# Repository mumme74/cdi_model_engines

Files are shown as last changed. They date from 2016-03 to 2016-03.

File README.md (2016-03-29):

# CDI for model engines
A CDI driven by 12v to be used by model engines

# Warning this project isnt tested nor testbuilt yet

Its for my brother next model engine that he's building, a Hoglet.

Features:
 * Should (in theory) support a 12Cyl up to 6000 rpm
 * 2 wire hallsensor solution (like a GME)
 * Hallsensor trigger output to optional other board (like a arduino)
 * Optionally trigger from a input instead of hallsensor (remove a solder bridge)
 
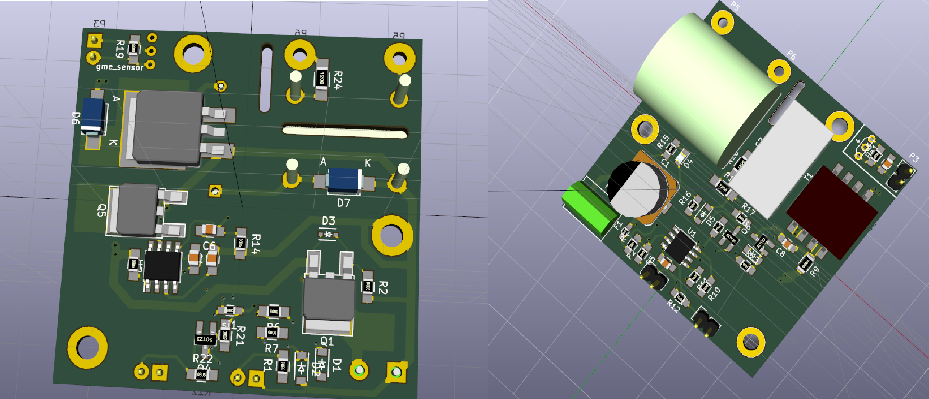
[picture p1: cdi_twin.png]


Should be able to run his challenger V8
https://www.youtube.com/watch?v=TyKyQjUpV_E

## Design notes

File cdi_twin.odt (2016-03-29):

CDI 12v

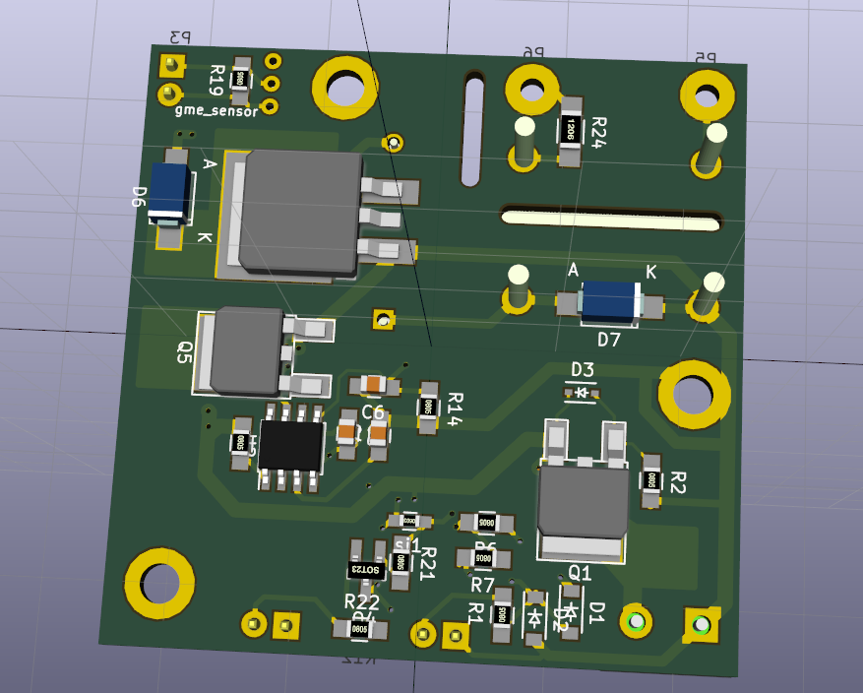
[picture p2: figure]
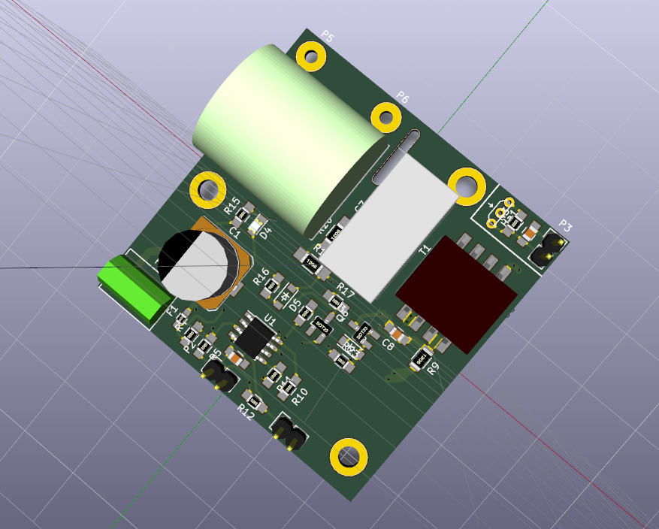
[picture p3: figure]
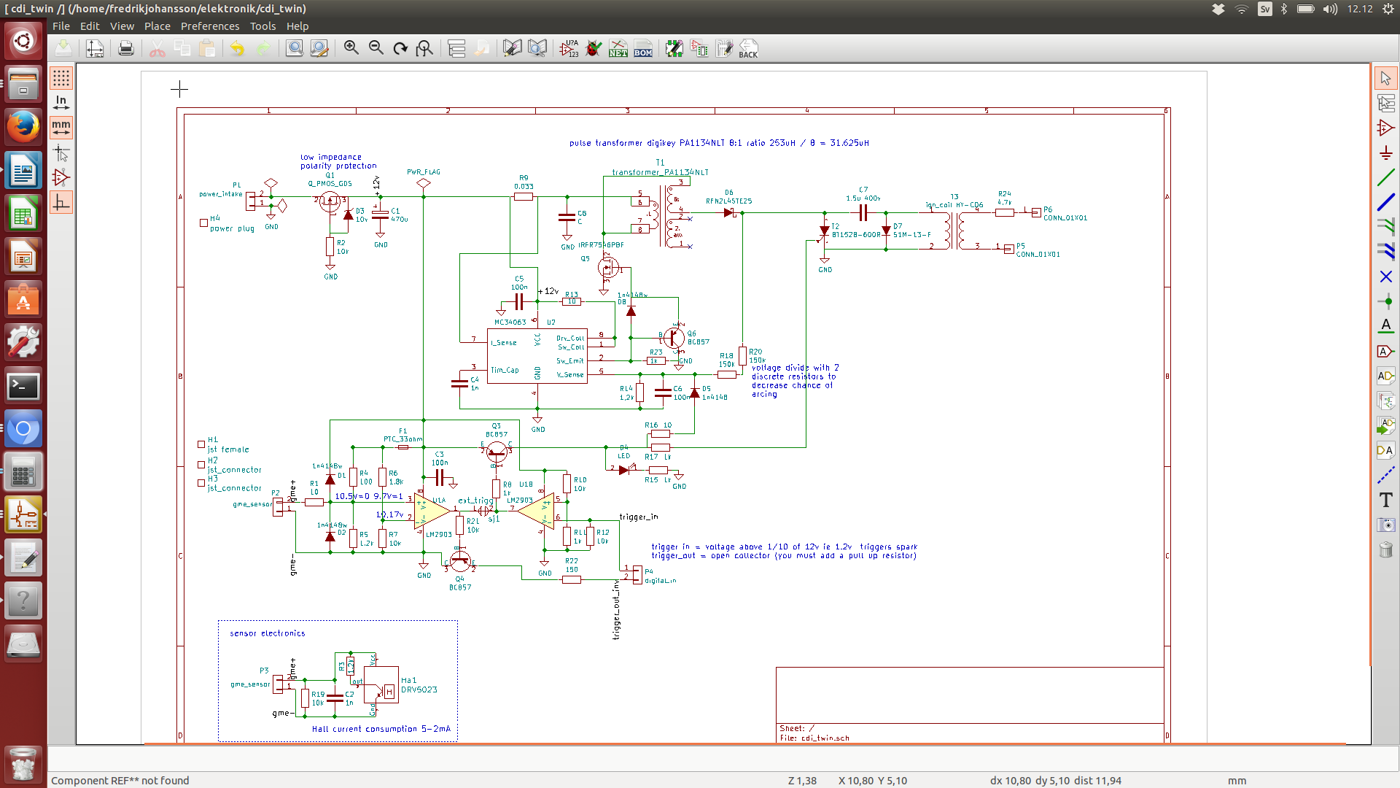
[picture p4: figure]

All prices are in SEK.
Index | Quantity | Image | Part Number | Description | Customer Reference | Available Quantity | Backorder Quantity | Unit Price | Extended Price
1 | | | 1N4148W-FDICT-ND (http://www.digikey.se/scripts/DkSearch/dksus.dll?Detail&itemSeq=193125955&uq=635947423000948024) | DIODE GEN PURP 100V 300MA SOD123 | | 4 Immediate | 0 | 1,37000 | 5,48 kr
2 | | | 296-1012-1-ND (http://www.digikey.se/scripts/DkSearch/dksus.dll?Detail&itemSeq=193125954&uq=635947423000948024) | IC DUAL DIFF COMP 8-SOIC | | 1 Immediate | 0 | 3,17000 | 3,17 kr
3 | | | 296-38520-ND (http://www.digikey.se/scripts/DkSearch/dksus.dll?Detail&itemSeq=193125950&uq=635947423000958024) | IC HALL SENSOR DGTL SW TO-92 | | 1 Immediate | 0 | 9,60000 | 9,60 kr
4 | | | 311-1.00KCRCT-ND (http://www.digikey.se/scripts/DkSearch/dksus.dll?Detail&itemSeq=193125953&uq=635947423000958024) | RES SMD 1K OHM 1% 1/8W 0805 | | 5 Immediate | 0 | 0,86000 | 4,30 kr
5 | | | 311-1.20KCRCT-ND (http://www.digikey.se/scripts/DkSearch/dksus.dll?Detail&itemSeq=193125949&uq=635947423000958024) | RES SMD 1.2K OHM 1% 1/8W 0805 | | 3 Immediate | 0 | 0,86000 | 2,58 kr
6 | | | 311-1.80KCRCT-ND (http://www.digikey.se/scripts/DkSearch/dksus.dll?Detail&itemSeq=193125951&uq=635947423000968024) | RES SMD 1.8K OHM 1% 1/8W 0805 | | 1 Immediate | 0 | 0,86000 | 0,86 kr
7 | | | 311-10.0CRCT-ND (http://www.digikey.se/scripts/DkSearch/dksus.dll?Detail&itemSeq=193125947&uq=635947423000968024) | RES SMD 10 OHM 1% 1/8W 0805 | | 3 Immediate | 0 | 0,86000 | 2,58 kr
8 | | | 311-10.0KCRCT-ND (http://www.digikey.se/scripts/DkSearch/dksus.dll?Detail&itemSeq=193125952&uq=635947423000968024) | RES SMD 10K OHM 1% 1/8W 0805 | | 6 Immediate | 0 | 0,86000 | 5,16 kr
9 | | | 311-100CRCT-ND (http://www.digikey.se/scripts/DkSearch/dksus.dll?Detail&itemSeq=193125946&uq=635947423000978024) | RES SMD 100 OHM 1% 1/8W 0805 | | 1 Immediate | 0 | 0,86000 | 0,86 kr
10 | | | 311-150CRCT-ND (http://www.digikey.se/scripts/DkSearch/dksus.dll?Detail&itemSeq=193125948&uq=635947423000978024) | RES SMD 150 OHM 1% 1/8W 0805 | | 1 Immediate | 0 | 0,86000 | 0,86 kr
11 | | | 311-150KERCT-ND (http://www.digikey.se/scripts/DkSearch/dksus.dll?Detail&itemSeq=193125944&uq=635947423000978024) | RES SMD 150K OHM 5% 1/4W 1206 | | 2 Immediate | 0 | 0,86000 | 1,72 kr
12 | | | 311-4.7ERCT-ND (http://www.digikey.se/scripts/DkSearch/dksus.dll?Detail&itemSeq=193125945&uq=635947423000988024) | RES SMD 4.7 OHM 5% 1/4W 1206 | | 1 Immediate | 0 | 0,86000 | 0,86 kr
13 | | | 408-1576-1-ND (http://www.digikey.se/scripts/DkSearch/dksus.dll?Detail&itemSeq=193125942&uq=635947423000988024) | RES SMD 0.033 OHM 1% 3/4W 1206 | | 1 Immediate | 0 | 4,63000 | 4,63 kr
14 | | | 455-1135-1-ND (http://www.digikey.se/scripts/DkSearch/dksus.dll?Detail&itemSeq=193125943&uq=635947423000988024) | CONN TERM CRIMP XH 22-28AWG | | 2 Immediate | 0 | 0,86000 | 1,72 kr
15 | | | 455-2247-ND (http://www.digikey.se/scripts/DkSearch/dksus.dll?Detail&itemSeq=193125938&uq=635947423000998024) | CONN HEADER XH TOP 2POS 2.5MM | | 2 Immediate | 0 | 1,29000 | 2,58 kr
16 | | | 455-2266-ND (http://www.digikey.se/scripts/DkSearch/dksus.dll?Detail&itemSeq=193125940&uq=635947423000998024) | CONN HOUSING 2.5MM 2POS | | 1 Immediate | 0 | 0,86000 | 0,86 kr
17 | | | 478-1328-1-ND (http://www.digikey.se/scripts/DkSearch/dksus.dll?Detail&itemSeq=193125939&uq=635947423001008024) | CAP CER 1000PF 50V NP0 0805 | | 3 Immediate | 0 | 0,86000 | 2,58 kr
18 | | | 478-3352-1-ND (http://www.digikey.se/scripts/DkSearch/dksus.dll?Detail&itemSeq=193125937&uq=635947423001008024) | CAP CER 0.1UF 50V X7R 0805 | | 3 Immediate | 0 | 0,86000 | 2,58 kr
19 | | | 490-2471-1-ND (http://www.digikey.se/scripts/DkSearch/dksus.dll?Detail&itemSeq=193125941&uq=635947423001008024) | THERMISTOR PTC 33 OHM SMD | | 1 Immediate | 0 | 4,63000 | 4,63 kr
20 | | | 493-6225-1-ND (http://www.digikey.se/scripts/DkSearch/dksus.dll?Detail&itemSeq=193125936&uq=635947423001018024) | CAP ALUM 470UF 20% 25V SMD | | 1 Immediate | 0 | 5,83000 | 5,83 kr
21 | | | 497-7851-1-ND (http://www.digikey.se/scripts/DkSearch/dksus.dll?Detail&itemSeq=193125935&uq=635947423001018024) | IC REG BUCK BOOST INV ADJ 8SOIC | | 1 Immediate | 0 | 4,80000 | 4,80 kr
22 | | | 553-1982-1-ND (http://www.digikey.se/scripts/DkSearch/dksus.dll?Detail&itemSeq=193125933&uq=635947423001018024) | XFRMR 5V 7W 253UH POE EP10 SMD | | 1 Immediate | 0 | 31,97000 | 31,97 kr
23 | | | 568-9619-1-ND (http://www.digikey.se/scripts/DkSearch/dksus.dll?Detail&itemSeq=193125931&uq=635947423001028024) | THYRISTOR 650V 20A D2PAK | | 1 Immediate | 0 | 10,20000 | 10,20 kr
24 | | | 732-4986-1-ND (http://www.digikey.se/scripts/DkSearch/dksus.dll?Detail&itemSeq=193125932&uq=635947423001028024) | LED GREEN CLEAR 0805 SMD | | 1 Immediate | 0 | 2,83000 | 2,83 kr
25 | | | BC857ALT1GOSCT-ND (http://www.digikey.se/scripts/DkSearch/dksus.dll?Detail&itemSeq=193125934&uq=635947423001028024) | TRANS PNP 45V 0.1A SOT-23 | | 3 Immediate | 0 | 1,03000 | 3,09 kr
26 | | | DMP3010LK3Q-13DICT-ND (http://www.digikey.se/scripts/DkSearch/dksus.dll?Detail&itemSeq=193125930&uq=635947423001038024) | MOSFET P-CH 30V 17A TO252 | | 1 Immediate | 0 | 5,31000 | 5,31 kr
27 | | | ED2828-ND (http://www.digikey.se/scripts/DkSearch/dksus.dll?Detail&itemSeq=193125929&uq=635947423001038024) | TERM BLOCK HDR 2POS R/A 5.08MM | | 1 Immediate | 0 | 2,31000 | 2,31 kr
28 | | | ED2908-ND (http://www.digikey.se/scripts/DkSearch/dksus.dll?Detail&itemSeq=193125925&uq=635947423001038024) | TERM BLOCK PLUG 2POS STR 5.08MM | | 1 Immediate | 0 | 7,54000 | 7,54 kr
29 | | | IRFR7546PBF-ND (http://www.digikey.se/scripts/DkSearch/dksus.dll?Detail&itemSeq=193125924&uq=635947423001048024) | MOSFET N-CH 60V 56A DPAK | | 1 Immediate | 0 | 7,03000 | 7,03 kr
30 | | | MM3Z10VT1GOSCT-ND (http://www.digikey.se/scripts/DkSearch/dksus.dll?Detail&itemSeq=193125926&uq=635947423001048024) | DIODE ZENER 10V 300MW SOD323 | | 1 Immediate | 0 | 1,20000 | 1,20 kr
31 | | | PCF1613-ND (http://www.digikey.se/scripts/DkSearch/dksus.dll?Detail&itemSeq=193125923&uq=635947423001048024) | CAP FILM 1.5UF 5% 450VDC RADIAL | | 1 Immediate | 0 | 6,86000 | 6,86 kr
32 | | | RFN2L4STE25CT-ND (http://www.digikey.se/scripts/DkSearch/dksus.dll?Detail&itemSeq=193125927&uq=635947423001058024) | DIODE SCHOTTKY 400V 1.5A PMDS | | 1 Immediate | 0 | 4,63000 | 4,63 kr
33 | | | S1M-FDICT-ND (http://www.digikey.se/scripts/DkSearch/dksus.dll?Detail&itemSeq=193125928&uq=635947423001058024) | DIODE GEN PURP 1KV 1A SMA | | 1 Immediate | 0 | 2,06000 | 2,06 kr
| | | | | | | | Subtotal | 153,27 kr
| | | | | | | | Shipping | 170,00 kr
| | | | | | | | Total | unknown

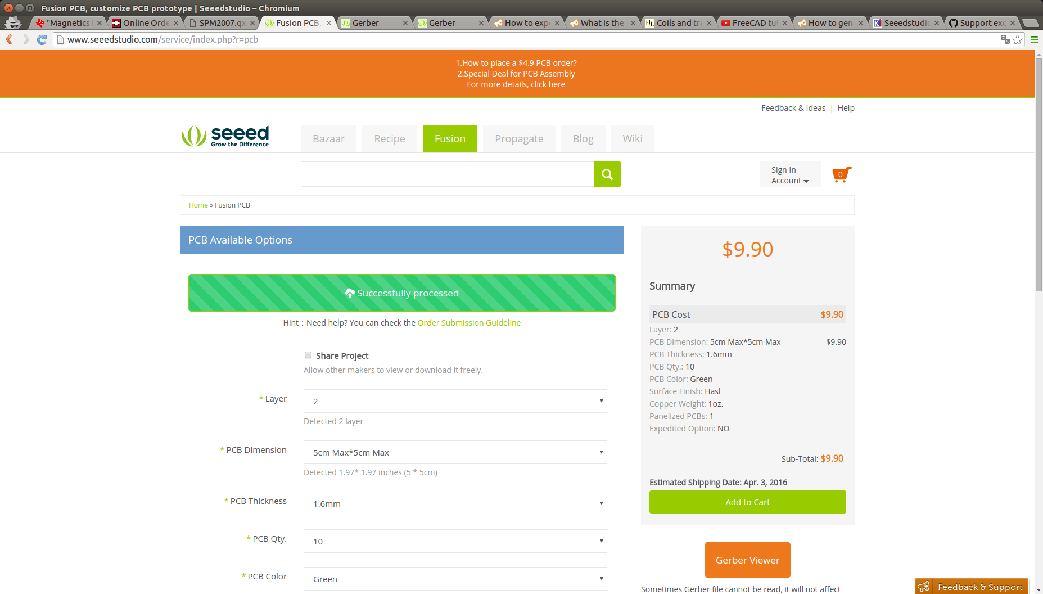
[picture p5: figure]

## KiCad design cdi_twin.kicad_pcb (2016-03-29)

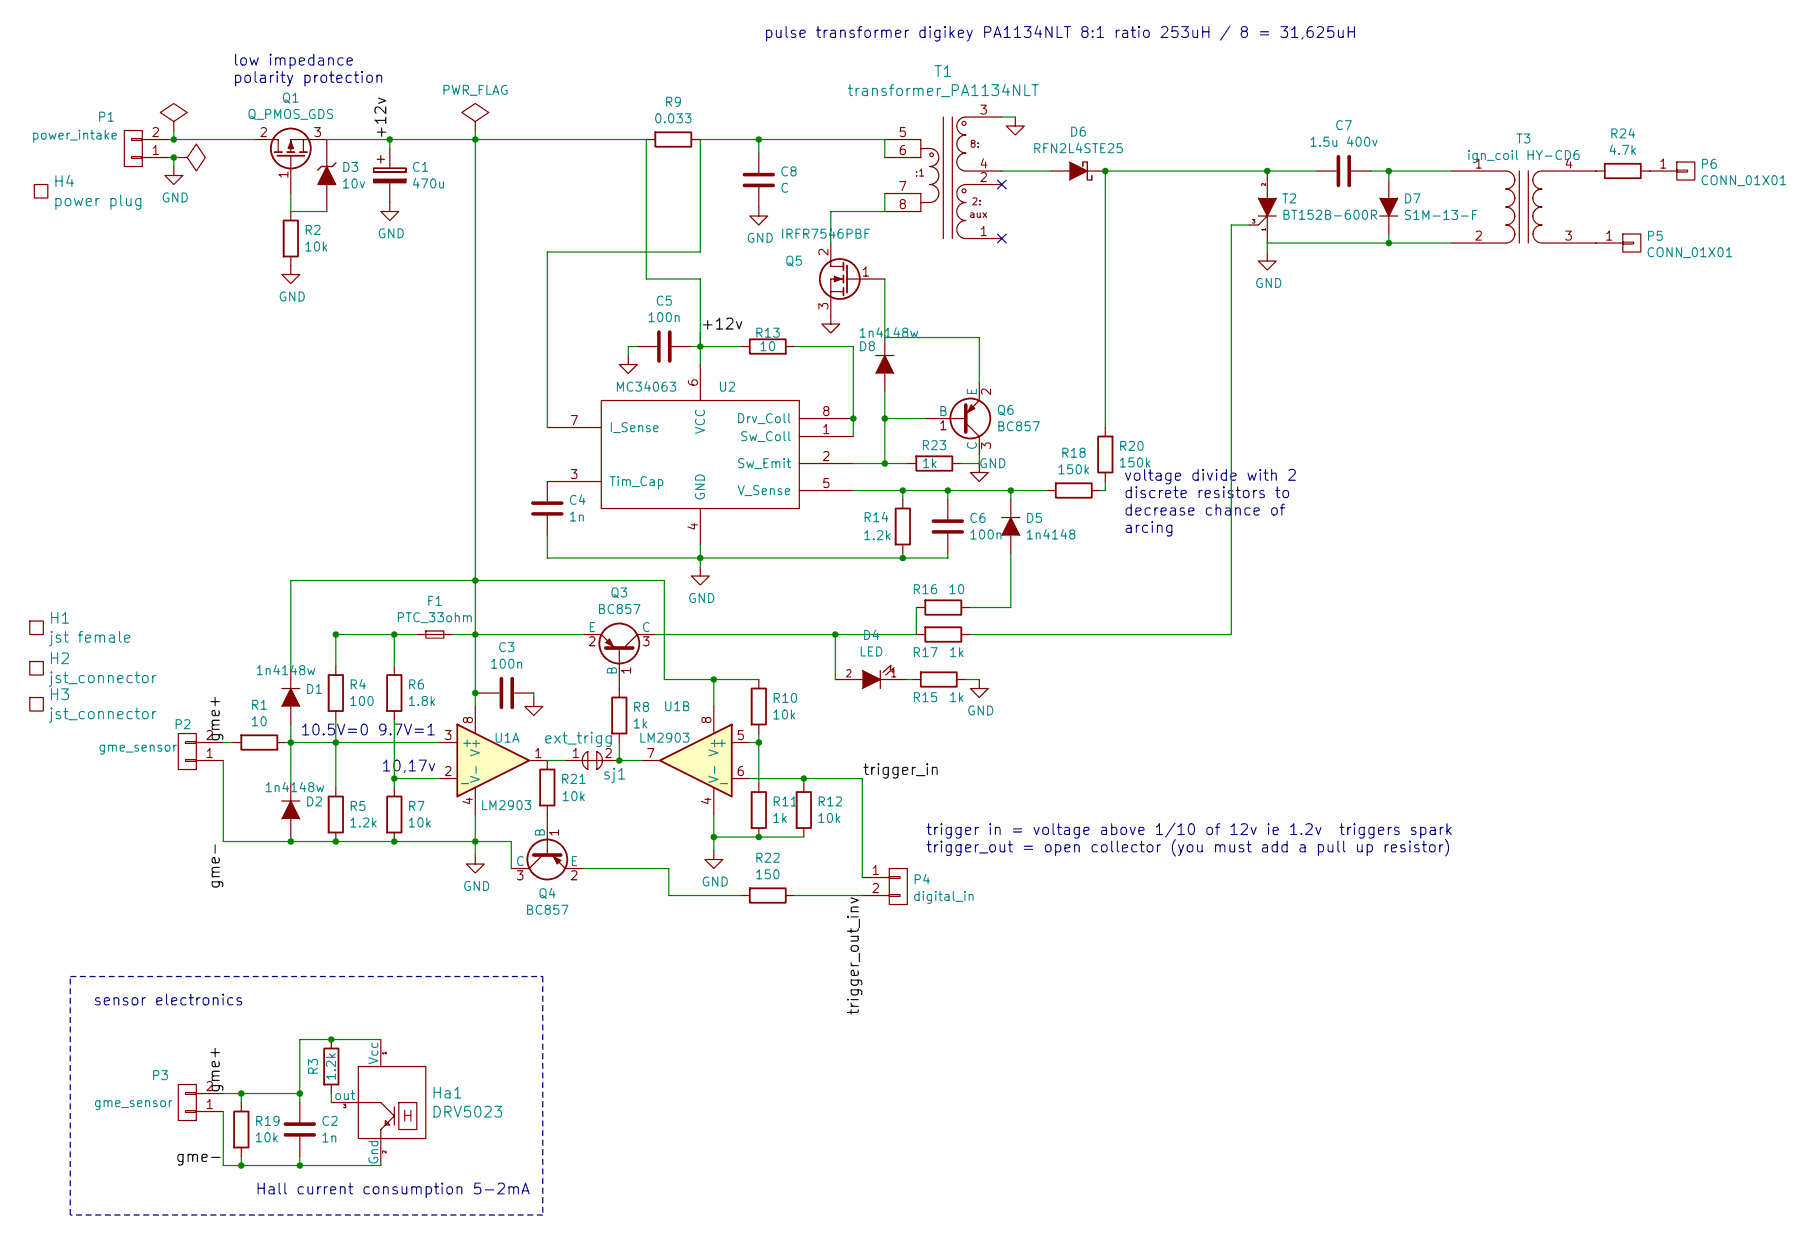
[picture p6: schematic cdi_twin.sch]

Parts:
C1: 470u; c_elec_10x10; digikey 493-6225-1-ND
C2, C4: 1n; C_0805_HandSoldering; digikey 478-1328-1-ND
C3, C5, C6: 100n; C_0805_HandSoldering; digikey 478-3352-1-ND
C7: 1.5u 400v; C_Rect_L18_W9_H15_P15; digikey PCF1613-ND
C8: C; C_0805_HandSoldering; digikey 478-1328-1-ND
D1, D2, D8: 1n4148w; SOD-123; digikey 1N4148W-FDICT-ND
D3: 10v; SOD-323; digikey MM3Z10VT1GOSCT-ND
D4: LED; LED_0805; digikey 732-4986-1-ND
D5: 1n4148; SOD-123; digikey 1N4148W-FDICT-ND
D6: RFN2L4STE25; SMA_Handsoldering; digikey RFN2L4STE25CT-ND
D7: S1M-13-F; SMA_Handsoldering; digikey S1M-FDICT-ND
F1: PTC_33ohm; R_0603_HandSoldering; digikey 490-2471-1-ND
H1: jst female; digikey 455-2266-ND
H2, H3: jst_connector; digikey 455-1135-1-ND
H4: power plug; digikey ED2908-ND
Ha1: DRV5023; hall_to92; digikey 296-38520-ND
P1: power_intake; bornier2; digikey ED2828-ND
P2: gme_sensor; Pin_Header_Straight_1x02; digikey 455-2247-ND
P3: gme_sensor; Pin_Header_Straight_1x02
P4: digital_in; Pin_Header_Straight_1x02; digikey 455-2247-ND
P5, P6: CONN_01X01; SolderWirePad_single_2mmDrill
Q1: Q_PMOS_GDS; TO-252-2Lead; digikey DMP3010LK3Q-13DICT-ND
Q3, Q4, Q6: BC857; SOT-23_Handsoldering; digikey BC857ALT1GOSCT-ND
Q5: IRFR7546PBF; TO-252-2Lead; digikey IRFR7546PBF-ND
R1, R13, R16: 10; R_0805_HandSoldering; digikey 311-10.0CRCT-ND
R2, R7, R10, R12, R19, R21: 10k; R_0805_HandSoldering; digikey 311-10.0KCRCT-ND
R3, R5, R14: 1.2k; R_0805_HandSoldering; digikey 311-1.20KCRCT-ND
R4: 100; R_0805_HandSoldering; digikey 311-100CRCT-ND
R6: 1.8k; R_0805_HandSoldering; digikey 311-1.80KCRCT-ND
R8, R11, R15, R17, R23: 1k; R_0805_HandSoldering; digikey 311-1.00KCRCT-ND
R9: 0.033; R_1206; digikey 408-1576-2-ND
R18, R20: 150k; R_1206_HandSoldering; digikey 311-150KERCT-ND
R22: 150; R_0805_HandSoldering; digikey 311-150CRCT-ND
R24: 4.7k; R_1206_HandSoldering; digikey 311-4.7ERCT-ND
T1: transformer_PA1134NLT; EP10_transformer; digikey 553-1982-1-ND
T2: BT152B-600R; TO-263-2Lead; digikey 568-9619-1-ND
T3: ign_coil HY-CD6; HY-CD6_trafo
U1: LM2903; SOIC-8_3.9x4.9mm_Pitch1.27mm; digikey 296-1012-1-ND
U2: MC34063; SOIC-8_3.9x4.9mm_Pitch1.27mm; digikey 497-7851-1-ND
sj1: ext_trigg; R_0603_HandSoldering

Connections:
/+12v: C1.1, C3.2, C5.1, D1.1 (K), D3.1 (K), F1.2, Q1.3 (S), Q3.2 (E), R9.2, R10.1, R13.1, U1.8 (V+), U2.6 (VCC)
/gme+: C2.1, Ha1.1 (Vcc), P2.2, P3.2, R1.2, R3.1, R19.1
/trigger_in: P4.1, R12.1, U1.6 (_)
/trigger_out_inv: P4.2, R22.1
GND: C1.2, C2.2, C3.1, C4.2, C5.2, C6.2, C8.2, D2.2 (A), D7.1 (K), Ha1.2 (Gnd), P1.1, P2.1, P3.1, Q4.3 (C), Q5.3 (S), Q6.3 (C), R2.2, R5.2, R7.2, R11.2, R12.2, R14.2, R15.1, R19.2, R23.1, T1.3, T2.1 (K), T3.2 (AB), U1.4 (V-), U2.4 (GND)
unnamed: C4.1, U2.3 (Tim_Cap)
unnamed: C6.1, D5.1 (K), R14.1, R18.2, U2.5 (V_Sense)
unnamed: C7.1, D7.2 (A), T3.1 (AA)
unnamed: C7.2, D6.1 (K), R20.2, T2.2 (A)
unnamed: C8.1, R9.1, T1.5, T1.6, U2.7 (I_Sense)
unnamed: D1.2 (A), D2.1 (K), R1.1, R4.2, R5.1, U1.3 (+)
unnamed: D3.2 (A), Q1.1 (G), R2.1
unnamed: D4.1 (K), R15.2
unnamed: D4.2 (A), Q3.3 (C), R16.2, R17.2
unnamed: D5.2 (A), R16.1
unnamed: D6.2 (A), T1.4
unnamed: D8.1 (K), Q5.1 (G), Q6.2 (E)
unnamed: D8.2 (A), Q6.1 (B), R23.2, U2.2 (Sw_Emit)
unnamed: F1.1, R4.1, R6.1
unnamed: Ha1.3 (out), R3.2
unnamed: P1.2, Q1.2 (D)
unnamed: P5.1, T3.3 (SA)
unnamed: P6.1, R24.1
unnamed: Q3.1 (B), R8.1
unnamed: Q4.1 (B), R21.2
unnamed: Q4.2 (E), R22.2
unnamed: Q5.2 (D), T1.7, T1.8
unnamed: R6.2, R7.1, U1.2 (_)
unnamed: R8.2, U1.7, sj1.2
unnamed: R10.2, R11.1, U1.5 (+)
unnamed: R13.2, U2.1 (Sw_Coll), U2.8 (Drv_Coll)
unnamed: R17.1, T2.3 (G)
unnamed: R18.1, R20.1
unnamed: R21.1, U1.1, sj1.1
unnamed: R24.2, T3.4 (SB)

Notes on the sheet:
low impedance polarity protection
sensor electronics
voltage divide with 2 discrete resistors to decrease chance of arcing
pulse transformer digikey PA1134NLT 8:1 ratio 253uH / 8 = 31,625uH
10,17v
10.5V=0 9.7V=1
Hall current consumption 5-2mA
trigger in = voltage above 1/10 of 12v ie 1.2v triggers spark trigger_out = open collector (you must add a pull up resistor)

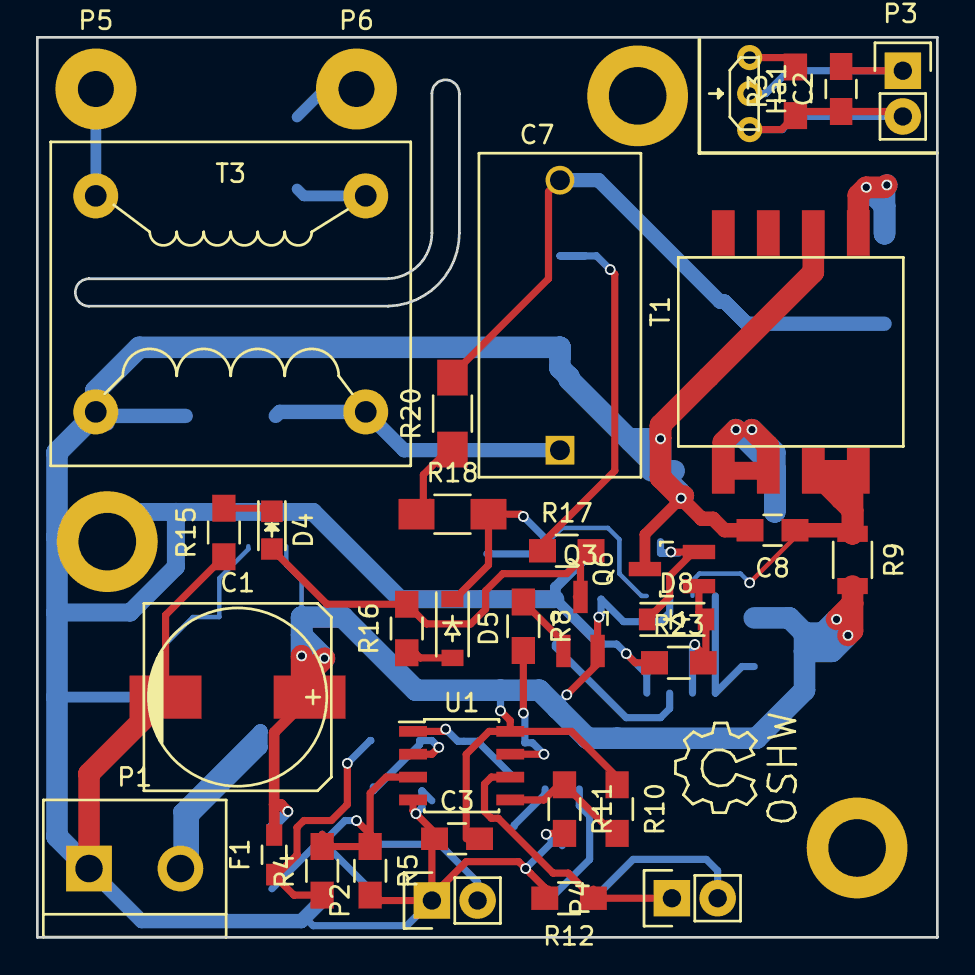
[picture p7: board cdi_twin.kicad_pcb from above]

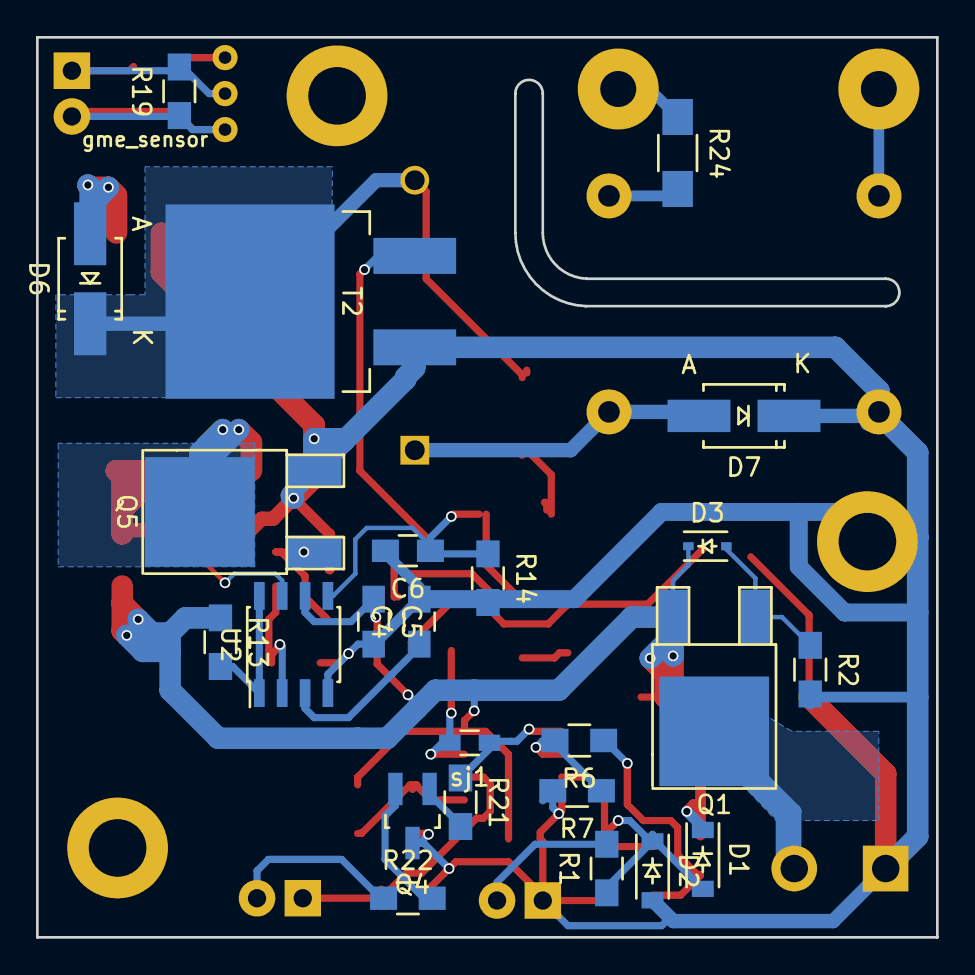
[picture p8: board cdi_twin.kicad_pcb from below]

Board: 2 copper layers, 50.0 x 50.0 mm, 59 parts (24 on the bottom side), 35 nets.
